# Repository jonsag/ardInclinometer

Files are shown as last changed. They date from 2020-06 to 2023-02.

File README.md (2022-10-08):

# ardInclinometer

An inclinometer built around MPU-6050 and ATmega MCUs  

Works on Arduino UNO, not working on barebone MCUs yet.

## Install latest avrdude from git repository

Install prerequisites  
>$ sudo apt install git build-essential cmake libelf-dev libusb-dev libusb-1.0-0-dev libhidapi-dev libftdi-dev libftdi1-dev flex bison  

Download repository  
>$ git clone [https://github.com/avrdudes/avrdude.git](https://github.com/avrdudes/avrdude.git)  

Build  
>$ cd avrdude  
>$ cmake -D CMAKE_BUILD_TYPE=Release -B build_linux  
>$ cmake --build build_linux  

Install (if you have ~/bin in your path)  
>$ cp -r build_linux/src ~/bin/avrdude-bin  
>$ ln -s avrdude-bin/avrdude ~/bin/avrdude  

Check version  
>$ avrdude -?  

    ...
    avrdude version 7.0-20220924 (8f478f0), URL: <https://github.com/avrdudes/avrdude>

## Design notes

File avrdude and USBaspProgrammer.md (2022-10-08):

# avrdude and USBaspProgrammer

## Hardware

### USBaspProgrammer

I'm using [my version](https://github.com/jonsag/usbaspprogrammer) of [Thomas Fischl's programmer](https://www.fischl.de/usbasp/)  

### ATmega board detector

Not necessary, but I find [this](https://github.com/jonsag/ardAVRProgrammer) useful  

### High voltage programmer

I use [this one](https://github.com/jonsag/ardHighVoltageProgrammer)  

## Software

### picocom

>$ picocom -b 115200 /dev/ttyUSB0 --omap crcrlf  

Exit with  
> [Ctrl+a] [Ctrl+x]

### cu

>$ cu -l /dev/ttyUSB0 -s 115200

Exit with
>~.

## Usage

### How to use avrdude

Check  
>$ avrdude -p m328p -c usbasp -v  

Read fuses  
>$ avrdude -p m328p -c usbasp -U lfuse:r:-:i -U hfuse:r:-:i -U efuse:r:-:i -v  

Erase flash  
$ /usr/bin/avrdude -p m328p -c usbasp -t  

    avrdude: AVR device initialized and ready to accept instructions  

    Reading | ################################################## | 100% 0.00s  

>avrdude> erase  

    >>> erase  
    avrdude: erasing chip  
    avrdude>  

or simply
>$ avrdude -p m88p -c usbasp -e  

#### Set fuses

Use [the calculator](https://www.engbedded.com/fusecalc/)  

>$ avrdude -p m328p -c usbasp -U lfuse:w:0xe2:m -U hfuse:w:0xdb:m -U efuse:w:0xfd:m -v

### Programming an ATmega328P  with external clock

Either you hook it up with an oscillator circuit, or you reset the fuses

#### Fuses examples (obtained with the ATmega board detector)

Example output of a programmed 328P with external clock  

    LFuse = 0xF7 
    HFuse = 0xD9 
    EFuse = 0xFC

An unprogrammed 328P with stock fuses

    LFuse = 0xE2 
    HFuse = 0xDB 
    EFuse = 0xFD

#### Use the high voltage programmer

>$ cu -l /dev/ttyUSB0 -s 9600

    Connected.
    Select mode:
    1: ATmega (28-pin)
    2: ATtiny2313
    3: ATtiny (8-pin) / HVSP
    Selected mode: ATMEGA
    Insert target AVR and press button.

    Existing fuse values:
    LFUSE: F7
    HFUSE: D6

    Enter desired LFUSE hex value (ie. 0x62): 62 (enter 0xE2)
    Enter desired HFUSE hex value (ie. 0xDF): 5B (enter 0xDA)
    Burning fuses...

    Read LFUSE: 62
    Read HFUSE: 5B
    Burn complete.

    It is now safe to remove the target AVR.

    Insert target AVR and press button.

Fuses OK (E:FD, H:DA, L:E2)  
Fuses OK (E:FD, H:D6, L:E2)  
Fuses OK (E:FD, H:D6, L:F7)  

## ATmega328 fuses

stock/empty ATmega328

    Signature = 0x1E 0x95 0x14 
    Processor = ATmega328
    Flash memory size = 32768 bytes.
    LFuse = 0xE2 
    HFuse = 0xDB 
    EFuse = 0xFF 
    Lock byte = 0xFF 
    Clock calibration = 0xA8 
    Bootloader in use: No
    EEPROM preserved through erase: No
    Watchdog timer always on: No
    Bootloader is 2048 bytes starting at 7800

with bootloader from arduino ide

    Signature = 0x1E 0x95 0x14 
    Processor = ATmega328
    Flash memory size = 32768 bytes.
    LFuse = 0xF7 
    HFuse = 0xD6 
    EFuse = 0xFD 
    Lock byte = 0xFF 
    Clock calibration = 0xA8 
    Bootloader in use: Yes
    EEPROM preserved through erase: Yes
    Watchdog timer always on: No
    Bootloader is 512 bytes starting at 7E00

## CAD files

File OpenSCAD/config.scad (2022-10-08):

// config.scad, configuration for ardInclinometer-ATmega328-casing.scad

print = true;

showBoard = true;

showBox = true;
showButtonRods = false;
showLid = false;

// PCB size in mm
pcbX = 66.675;
pcbY = 55.580;
pcbZ = 1.6;

pcbZadj = 0;
boardZ = 13.8 + pcbZadj;

displayX = 25.400;
displayY = 10.050;

displayXoffset = -3.165 / 2;
displayYoffset = 12.420 / 2;

ledDia = 5.5;

buttonRodDia = 5;
buttonRodStickOut = 0;
buttonGuideZ = 9.2 + pcbZadj;

ledTunnelZ = 12 + pcbZadj;

// outer shell
wallThickness = 1;

boxCornerRadius = 5;

// lid
lidClearance = 0.5;
lidScrewHoleDia = 3.5;
lidScrewHeadDia = 5;

textFont = "Liberation Sans:style=Bold";
textSize1 = 5;
textSize2 = 2.5;
textSize3 = 5;
textSize4 = 3;

text1 = "ardInclinometer";
text2 = "github.com/jonsag/ardInclinometer";

// screw posts
lidPostDia = boxCornerRadius * 2;
lidPostHoleDia = 5;
lidPostInset = 1;

pcbPostZ = 15.75 + pcbZadj;
pcbPostDia = 7.5;
pcbPostHoleDia = 5;

// casing measurements
extraSpace = 1;

boxX = pcbX + wallThickness * 2 + extraSpace * 2;
boxY = pcbY + wallThickness * 2 + extraSpace * 2;
boxZ = 35;

lidPostZ = boxZ - pcbPostZ - pcbZ;

roundness = 100;

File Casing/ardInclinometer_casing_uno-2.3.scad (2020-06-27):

// ardInclinometer_casing

// Casing for the ardInclinometer project
// This holds the MPU605 with it's gimbal,
// an arduino, OLED

// what should we draw:
casing = true;
lid = false;

mount1 = false;
mount2 = false;
mount3 = false;

disableAdjustmentHoles = false;

// lay out everything for printing
print = true;

// main body
// width = X, depth = Z, height = Y
width = 125;
depth = 115;
height = 45;

wallThickness = 3;

// oversize factor
overSizeFactor = 1.05; // useful for when making holes, larger than 1

// battery compartment
batteryHeight = 55;
batteryWidth = 20;

// screen wedge
wedgeHeight = 30;

// push buttons
include <push_button.scad>

pushButtonHoleDia = 7;

pushButtonDist = 15;

buttonsXPlaceFactor = 0.295; // a value between 0 and 1
buttonsYPlaceFactor = 0.35;

// power switch
include <power_switch.scad>

totalWidth = 20;
holeWidth = 10.5;
holeDepth = 7;
screwHoleWidth = 15;
screwHoleDia = 2;
knobHoleWidth = 6;
knobDepth = 3;
knobWidth = 3;
knobHeight = 5;
mountPlateHeight = 0.5;
bodyHeight = 5;
legWidth = 1.5;
legDepth = 0.5;
legLength = 3;
legSpacing = 2.54;

// LEDs
include <led.scad>

ledDia = 5;

ledDist = 7; // distance between the leds

ledsXPlaceFactor = 0.355;
ledsYPlaceFactor = 1.5;

// screen cut out and screw posts
screenPostHoriDist = 20;
screenPostVertDist = 22;

screenPostDia = 4;
screenPostHeight = 3;

screenPostHoleDia = 2.5;
screenPostHoleDepth = 3;

screenWidth = 23;
screenHeight = 11.5;
screenOffset = 2.25;

screenCoverOverSize = 1;
screenCoverRecess = 2;

screenXPlaceFactor = 0.75; // a value between 0 and 1
     
// lid screw posts
lidPostDia = 10;
lidPostHoleDia = 2.5;

lidPostHoleDepth = 10;

lidPostOffset = -1; // extra distance from walls to screw posts

// lid
lidThickness = 5;
lidRest = 3;

lidGap = 0.5; // gap between lid and casing

lidScrewHoleDia = 3.5;
lidScrewHeadDia = 6;
lidScrewCountersink = 3;

lidRecess = 2;

// print text on lid
textOnLid1 = "ardInclinometer";
textOnLid2 = "by Jon Sagebrand";

lidTextFont = "Liberation Sans:style=Bold Italic";
lidFontSize = 6;

// mpu6050
include <mpu_mount-2.0.scad>;

adjustmentHoleDia = 3;

// pcb mount
pcbLength = 81.28;
pcbWidth = 45.085;

pcbMountEdgeDist = 3.175;

pcbMountPostHeight = 10;
pcbMountPostDia = 6;

pcbMountScrewDia = 3;

// uno
include <Arduino.scad>

unoPostHeight = 5;
unoPostDia = 6;

//mpu6050_mount();
if (!print) {
     translate([mount1Width / 2 + wallThickness + lidPostDia + lidPostOffset, (mount1Height  + swivelWidth) * 3 + wallThickness - swivelWidth, mount3Depth / 2 + mount3ExtraDepth + wallThickness])
	  rotate([-90, 0, 0])
	  union() {
	  if (mount1) {
	       mount1();
	  }
	  if (mount2) {
	       translate([0, 0, -swivelWidth - mount1Height])
		    mount2();
	  }
	  if (mount3) {
               translate([0, 0, -swivelWidth * 2 - mount1Height * 2])
                    mount3();
	  }
	  if (!print) {
	       translate([-10.5, -7.8 + mount1YMove, mount1Height / 2 - 1.2])
		    mpu6050_gy521();
	  }
     }
} else {
     if (mount1) {
	  translate([width + mount1Width / 2 + 2, mount1Depth / 2, mount1Height / 2 + swivelWidth])
	       mount1();
     }
     if (mount2) {
	  translate([width + mount2Width/ 2 + 2, mount1Depth / 2 + mount2Depth + 2 + mount1YMove, mount2Height / 2 + swivelWidth])
	       mount2();
     }

     if (mount3) {
          translate([width + mount2Width / 2 + 2, mount1Depth / 2 + mount2Depth + 2 + mount2ExtraDepth + 2 + mount2Depth + 2, mount3Height / 2])
               mount3();
     }
}

// roundness
$fn=100;

// start drawing
if (casing) { // create the main body
     union() { // union of drilled main body, screen wedge with cut out and screen screw posts
	  difference() { // drill lid posts screw holes and cut off wedge for screen mount
	       union() { // union of main body, lid rests and screw posts
		    difference() {
			 cube([width, depth, height]); // create the main body
			 
			 // hollow out the casing
			 translate([wallThickness, wallThickness, wallThickness])
			      cube([width - 2 * wallThickness, depth - 2 * wallThickness, height]);			      
		    }
		    lidRests(); // add the prisms where the lid is resting
		    
		    screwPosts(); // add the screwposts where to screw down the lid

		    powerSwitchMount();
	       }
	       screwPostHoles(); // drill the holes in the screw posts
	       
	       wedgeCutOff(0); // cut off the wedge where the screen lies

	       powerSwitchHoles();
	  }
	  
	  difference() {
	       wedgeCutOff(0); // create the cutoff again, this time it's solid
	       
	       wedgeCutOff(wallThickness * sqrt(2)); // move the wedge and cut off again
	       
	       screenCutOut(); // cut out for the screen and screen cover

	       pushButtonHoles(); // drill the holes for the pushbutton

	       ledHoles();
	       
	       if (!disableAdjustmentHoles) {
		    adjustmentHoles(); // drill the holes where to insert an adjustment tool
	       }
	  }
	  pushButtons();

	  leds();
	  
	  screenPosts(); // add screw posts for the screen

	  add_mount4(); // add mount for the mpu

	  batteryCompartment(); // add battercompartment

	  //pcbMount(); // add PCB mount posts

	  unoMount(); // the mount posts for the arduino uno
     }
}

module unoMount() {
     translate([width - wallThickness - 69 - 2, batteryWidth + wallThickness * 2 + lidRest + 53 + 2, wallThickness + unoPostHeight])
	  rotate([0, 0, -90])
	  union() {
	  unoMountPosts(unoPostHeight, unoPostDia);
	  
	  if (!print) {
	       arduinoUno();
	  }
     }    
}


if (lid) { // create the lid
     if (print) {
	  translate ([wallThickness + lidGap, depth + 2, 0])
	       drawLid();
     } else {
	  translate ([wallThickness + lidGap, wallThickness + lidGap, height - lidThickness])
	       drawLid();
     }
}

if (!print) {
     translate([width * screenXPlaceFactor, depth - wedgeHeight / 2 - 1, wedgeHeight / 2 + 3]) // this placement is just an estimation, not critical
	  rotate([-45, 180, 0])
	  translate([-12.5, -13.5, -1.6])
	  GM009605v4();
}

module pcbMount() {
     translate([width - wallThickness - pcbLength / 2 - 3, depth - wedgeHeight - pcbWidth / 2, wallThickness + pcbMountPostHeight / 2])
	  union() {
     if (!print) { // PCB
	  translate([0, 0, pcbMountPostHeight / 2 + 0.6])
	       difference() {
	       color([30/255, 114/255, 198/255])
		    cube([pcbLength, pcbWidth, 1.2], center = true);

	       translate([-pcbLength / 2 + pcbMountEdgeDist, -pcbWidth / 2 + pcbMountEdgeDist, 0])
		    cylinder(1.2, (pcbMountScrewDia + 0.5) / 2, (pcbMountScrewDia + 0.5) / 2, center = true);

	       translate([pcbLength / 2 - pcbMountEdgeDist, -pcbWidth / 2 + pcbMountEdgeDist, 0])
                    cylinder(1.2, (pcbMountScrewDia + 0.5) / 2, (pcbMountScrewDia + 0.5) / 2, center = true);

	       translate([pcbLength / 2 - pcbMountEdgeDist, pcbWidth / 2 - pcbMountEdgeDist, 0])
                    cylinder(1.2, (pcbMountScrewDia + 0.5) / 2, (pcbMountScrewDia + 0.5) / 2, center = true);
	       }
     }

     difference() {
	  union() { // pcb mount posts
	       translate([-pcbLength / 2 + pcbMountEdgeDist, -pcbWidth / 2 + pcbMountEdgeDist, 0])
                    cylinder(pcbMountPostHeight, pcbMountPostDia / 2, pcbMountPostDia / 2, center = true);
	       
               translate([pcbLength / 2 - pcbMountEdgeDist, -pcbWidth / 2 + pcbMountEdgeDist, 0])
                    cylinder(pcbMountPostHeight, pcbMountPostDia / 2, pcbMountPostDia / 2, center = true);
	       
               translate([pcbLength / 2 - pcbMountEdgeDist, pcbWidth / 2 - pcbMountEdgeDist, 0])
                    cylinder(pcbMountPostHeight, pcbMountPostDia / 2, pcbMountPostDia / 2, center = true);

	       translate([-pcbLength / 2 + pcbMountEdgeDist, pcbWidth / 2 - pcbMountEdgeDist, 0])
                    cylinder(pcbMountPostHeight, pcbMountPostDia / 2, pcbMountPostDia / 2, center = true);
	  }
	  union() { // pcb mount posts drill holes                                                         
               translate([-pcbLength / 2 + pcbMountEdgeDist, -pcbWidth / 2 + pcbMountEdgeDist, 0])
                    cylinder(pcbMountPostHeight, (pcbMountScrewDia - 0.5) / 2, (pcbMountScrewDia - 0.5) / 2, center = true);

               translate([pcbLength / 2 - pcbMountEdgeDist, -pcbWidth / 2 + pcbMountEdgeDist, 0])
                    cylinder(pcbMountPostHeight, (pcbMountScrewDia - 0.5) / 2, (pcbMountScrewDia - 0.5) / 2, center = true);

               translate([pcbLength / 2 - pcbMountEdgeDist, pcbWidth / 2 - pcbMountEdgeDist, 0])
                    cylinder(pcbMountPostHeight, (pcbMountScrewDia - 0.5) / 2, (pcbMountScrewDia - 0.5) / 2, center = true);

               translate([-pcbLength / 2 + pcbMountEdgeDist, pcbWidth / 2 - pcbMountEdgeDist, 0])
                    cylinder(pcbMountPostHeight, (pcbMountScrewDia - 0.5) / 2, (pcbMountScrewDia - 0.5) / 2, center = true);
          }

     }
     }
     
}
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

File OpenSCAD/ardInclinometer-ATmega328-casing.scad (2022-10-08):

// ardInclinometer-ATmega328-casing.scad

include <./config.scad>
include <./roundedcube.scad>

module drawAll()
{
	if (showBoard && !print)
		drawBoard();

	if (showBox)
		drawBox();

	if (showButtonRods)
	{
		rodsZ = print ? buttonGuideZ + wallThickness * 1.5 : 0;

		rodsRotY = print ? 180 : 0;

		translate([ 0, 0, rodsZ - buttonRodStickOut - 0.3 ])
		rotate([ 0, rodsRotY, 0 ])
		drawButtonRods();
	}

	if (showLid)
	{
		lidX = print ? boxX * 2 : 0;
		lidZ = print ? boxZ : 0;

		lidRotY = print ? 180 : 0;

		translate([ lidX, 0, lidZ ])
		rotate([ 0, lidRotY, 0 ])
		drawLid();
	}
}

module drawBoard()
{
	color("blue") translate([ boxX / 2 + pcbX / 2, boxY / 2 - pcbY / 2, boardZ + wallThickness ])
	rotate([ 0, 180, 0 ])
	import("../KiCad/ardInclinometer-ATmega328/ardInclinometer-ATmega328-0.1-origin.stl", convexity = 5);
}

module drawBox()
{
	translate([ 0, 0, 0 ])
	{
		difference()
		{
			union() // this is added
			{
				difference()
				{
					roundedcube([ boxX, boxY, boxZ ], false, boxCornerRadius, "z");

					translate([ wallThickness, wallThickness, wallThickness ])
					roundedcube([ boxX - wallThickness * 2, boxY - wallThickness * 2, boxZ ], false, boxCornerRadius,
					            "z");

					// LED holes
					for (i = [-6.985 * 2:6.985:6.985 * 2])
					{
						translate([ boxX / 2 + i - 2.2225, boxY / 2 - 14.46, -wallThickness / 2 ])
						// translate([ boxX / 2 + pcbX / 2, boxY / 2 - pcbY / 2, boardZ ])
						cylinder(h = wallThickness * 2, d = ledDia, center = false, $fn = roundness);
					}

					// button holes
					for (i = [-8.255 * 2:8.255:8.255 * 2])
					{
						translate([ boxX / 2 - 28.2575, boxY / 2 + i, -wallThickness / 2 ])
						cylinder(h = wallThickness * 2, d = buttonRodDia + 0.5, center = false, $fn = roundness);
					}
				}

				// pcb screw posts
				for (i = [3.81:pcbX - 3.81 * 2:pcbX - 3.81])
				{
					for (j = [3.81:pcbY - 3.81 * 2:pcbY - 3.81])
					{
						translate(
						    [ i + boxX / 2 - pcbX / 2, j + boxY / 2 - pcbY / 2, pcbPostZ / 2 - wallThickness / 2 ])
						difference()
						{
							cylinder(h = pcbPostZ - wallThickness, d = pcbPostDia, center = true, $fn = roundness);
							translate([ 0, 0, wallThickness ])
							color("red") cylinder(h = pcbPostZ, d = pcbPostHoleDia, center = true, $fn = roundness);
						}
					}
				}

				// LED tunnels
				for (i = [-6.985 * 2:6.985:6.985 * 2])
				{
					translate([ boxX / 2 + i - 2.2225, boxY / 2 - 14.46, 0 ])
					difference()
					{
						cylinder(h = ledTunnelZ, d = ledDia + 2.5, center = false, $fn = roundness);
						translate([ 0, 0, -wallThickness / 2 ])
						cylinder(h = ledTunnelZ + wallThickness, d = ledDia + 0.5, center = false, $fn = roundness);
					}
				}

				// button guides
				for (i = [-8.255 * 2:8.255:8.255 * 2])
				{
					translate([ boxX / 2 - 28.2575, boxY / 2 + i, 0 ])
					difference()
					{
						cylinder(h = buttonGuideZ, d = buttonRodDia + wallThickness * 4, center = false,
						         $fn = roundness);
						translate([ 0, 0, -wallThickness / 2 ])
						cylinder(h = ledTunnelZ + wallThickness, d = buttonRodDia + 0.5, center = false,
						         $fn = roundness);
					}
				}
			}

			// this will be deleted

			// display hole
			color("red") translate([
				boxX / 2 - displayX / 2 + displayXoffset, boxY / 2 - displayY / 2 + displayYoffset, -wallThickness / 2
			])
			cube(size = [ displayX, displayY, wallThickness * 2 ], center = false);
			//}

			// LED text
			for (i = [-6.985 * 2:6.985:6.985 * 2])
			{
				color("red") translate([ boxX / 2 + i - 2.2225, boxY / 2 - 14.46 - 7, -wallThickness * 1.5 ])
				linear_extrude(wallThickness * 2)

				    if (i == -6.985 * 2)
				{
					text(text = "++", font = textFont, size = textSize3, valign = "center", halign = "center");
				}
				else if (i == -6.985)
				{
					text(text = "+", font = textFont, size = textSize3, valign = "center", halign = "center");
				}
				else if (i == 0)
				{
					text(text = "0", font = textFont, size = textSize3, valign = "center", halign = "center");
				}
				else if (i > 6.084 && i < 6.986)
				{
					text(text = "-", font = textFont, size = textSize3, valign = "center", halign = "center");
				}
				else if (i == 6.985 * 2)
				{
					text(text = "--", font = textFont, size = textSize3, valign = "center", halign = "center");
				}
			}

			// X arrow
			color("red") translate([ boxX - 5, 5, wallThickness / 2 ])
			rotate([ 0, 180, 0 ])
			linear_extrude(wallThickness * 2)
			    text(text = "-----> X", font = textFont, size = textSize4, valign = "center", halign = "left");

			// Z arrow
			for (i = [0:textSize4 + 2:(textSize4 + 2)])
			{
				color("red") translate([ boxX - 5, 5 + textSize4 + 2 + i, wallThickness / 2 ])
				rotate([ 0, 180, 0 ])
				linear_extrude(wallThickness * 2)
				    text(text = "|", font = textFont, size = textSize4, valign = "center", halign = "left");
			}

			color("red") translate([ boxX - 4.5, 5 + textSize4 + 2 * 5, wallThickness / 2 ])
			rotate([ 0, 180, 0 ])
			linear_extrude(wallThickness * 2)
			    text(text = "^", font = textFont, size = textSize4, valign = "center", halign = "left");

			color("red") translate([ boxX - 4.5, 5 + textSize4 + 2 * 7, wallThickness / 2 ])
			rotate([ 0, 180, 0 ])
			linear_extrude(wallThickness * 2)
			    text(text = "Z", font = textFont, size = textSize4, valign = "center", halign = "left");

			// Y arrow
			color("red") translate([ boxX - wallThickness / 2, 5, 5 ])
			rotate([ 0, 90, 0 ])
			linear_extrude(wallThickness * 2)
			    text(text = "Y <-----", font = textFont, size = textSize4, valign = "center", halign = "right");

			// button text
			for (i = [-8.255 * 2:8.255:8.255 * 2])
			{
				color("red") translate([ boxX / 2 - 28.2575 + 5, boxY / 2 + i, wallThickness * 0.5 ])
				rotate([ 0, 180, 0 ])
				linear_extrude(wallThickness * 2)

				    /*if (i == -8.255 * 2)
				    {
				        text(text = "X", font = textFont, size = textSize3, valign = "center", halign = "left");
				    }
				    else*/
				    if (i == -8.255)
				{
					text(text = "ALL", font = textFont, size = textSize2, valign = "center", halign = "right");
				}
				else if (i == 0)
				{
					text(text = "Z", font = textFont, size = textSize3, valign = "center", halign = "right");
				}
				else if (i > 8.254 && i < 8.256)
				{
					text(text = "Y", font = textFont, size = textSize3, valign = "center", halign = "right");
				}
				else if (i == 8.255 * 2)
				{
					text(text = "X", font = textFont, size = textSize3, valign = "center", halign = "right");
				}
			}
		}
	}
}

module drawButtonRods()
{
	for (i = [-8.255 * 2:8.255:8.255 * 2])
	{
		color("black") translate([ boxX / 2 - 28.2575, boxY / 2 + i, -wallThickness / 2 - buttonRodStickOut * 2 - 0.3 ])
		union()
		{
			cylinder(h = buttonGuideZ + wallThickness + buttonRodStickOut, d = buttonRodDia - 0.5);
			translate([ 0, 0, buttonGuideZ + wallThickness + buttonRodStickOut ])
			cylinder(h = wallThickness, d = buttonRodDia + wallThickness * 2);
		}
	}
}

module drawLid()
{
	difference()
	{
		color("lightgreen")
		    translate([ wallThickness + lidClearance / 2, wallThickness + lidClearance / 2, boxZ - wallThickness ])
		union()
		{
			roundedcube(
			    [ boxX - wallThickness * 2 - lidClearance, boxY - wallThickness * 2 - lidClearance, wallThickness ],
			    false, boxCornerRadius, "z");

			// pcb screw posts
			for (i = [3.81:pcbX - 3.81 * 2:pcbX - 3.81])
			{
				for (j = [3.81:pcbY - 3.81 * 2:pcbY - 3.81])
				{
					translate(
					    [ i + boxX / 2 - pcbX / 2, j + boxY / 2 - pcbY / 2, 0 ]) // pcbPostZ / 2 - wallThickness / 2 ])
					translate([ -wallThickness - lidClearance / 2, -wallThickness - lidClearance / 2, -lidPostZ / 2 ])
					cylinder(h = lidPostZ, d = pcbPostDia, center = true, $fn = roundness);
				}
			}
		}

		// text on lid
		color("red") translate([ boxX / 2, boxY / 2 + textSize1, boxZ - wallThickness / 2 ])
		linear_extrude(wallThickness)
		    text(text = str(text1), font = textFont, size = textSize1, valign = "center", halign = "center");

		color("red") translate([ boxX / 2, boxY / 2 - textSize2, boxZ - wallThickness / 2 ])
		linear_extrude(wallThickness)
		    text(text = str(text2), font = textFont, size = textSize2, valign = "center", halign = "center");
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

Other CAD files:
OpenSCAD/roundedcube.scad
OpenSCAD/Uno casing/ardInclinometer_casing.scad
OpenSCAD/Uno casing/ardInclinometer_casing_uno.scad
OpenSCAD/Uno casing/mpu_mount.scad

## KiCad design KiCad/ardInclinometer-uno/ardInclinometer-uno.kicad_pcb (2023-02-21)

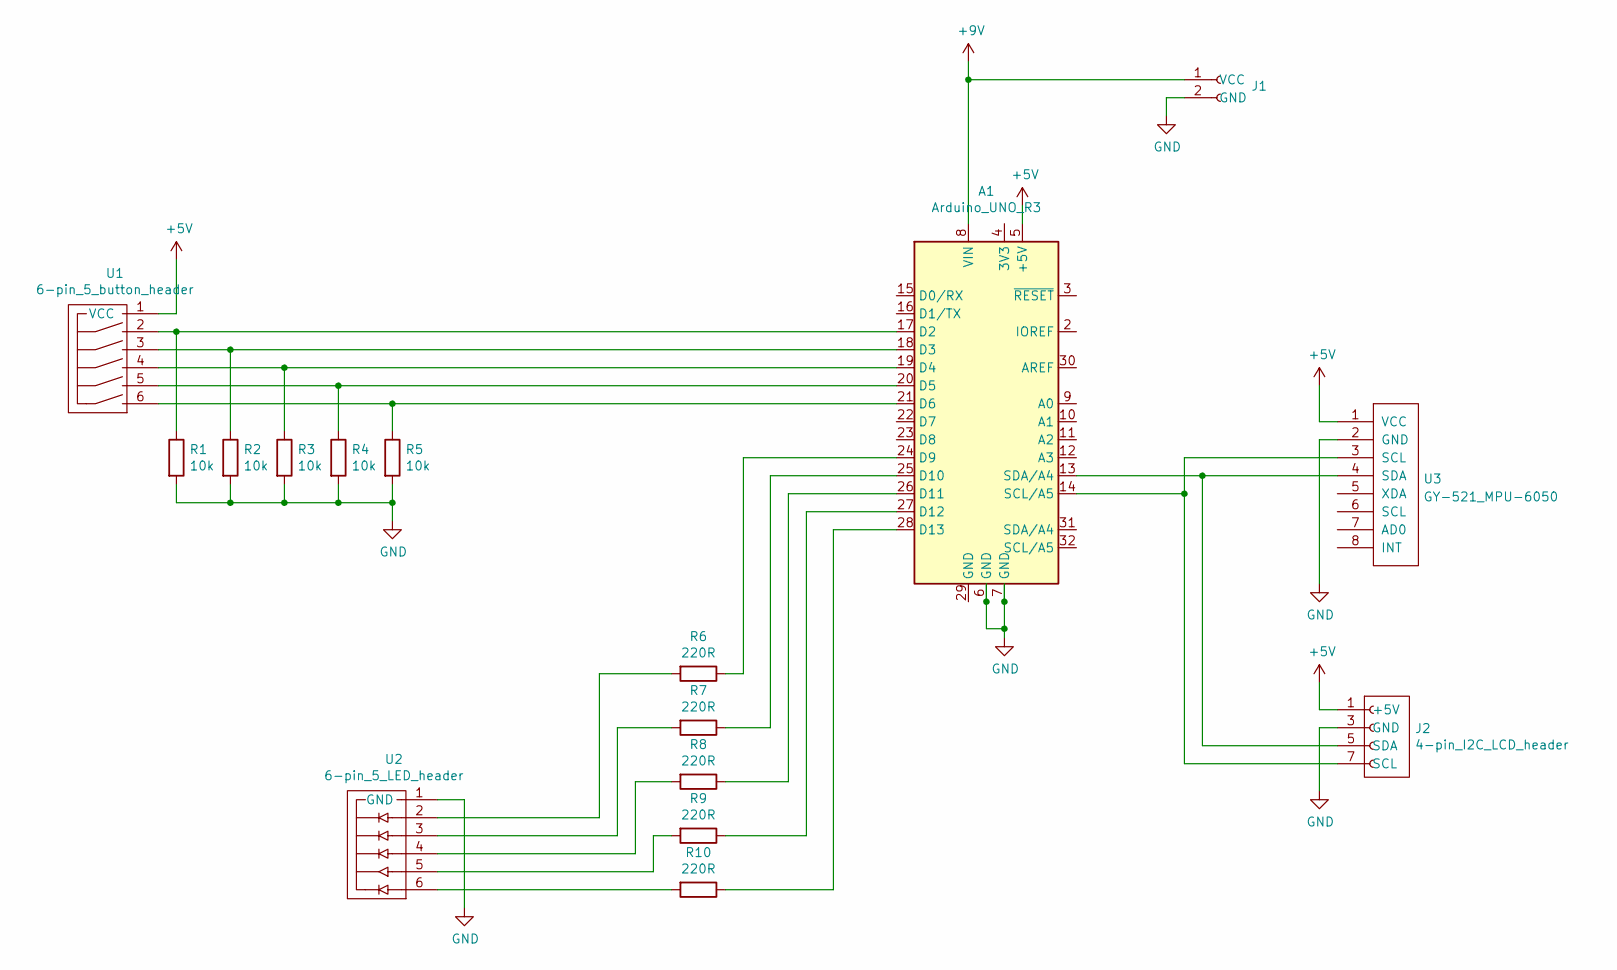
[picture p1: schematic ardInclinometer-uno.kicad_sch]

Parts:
A1: Arduino_UNO_R3; Arduino_UNO_R3_shield_large
J1: 2-pin_power_input_header; 2-pin_power_input_header_larger_pads
J2: 4-pin_I2C_LCD_header; 4-pin_I2C_LCD_header_larger
R1, R2, R3, R4, R5: 10k; R_Axial_DIN0207_L6.3mm_D2.5mm_P10.16mm_Horizontal_larger_pa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
R6, R7, R8, R9, R10: 220R; R_Axial_DIN0207_L6.3mm_D2.5mm_P10.16mm_Horizontal_larger_pa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
U1: 6-pin_5_button_header; 6-pin_5_switch_header_large
U2: 6-pin_5_LED_header; 6-pin_5_LED_header_large
U3: GY-521_MPU-6050

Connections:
+5V: A1.5 (+5V), J2.1 (+5V), U1.1 (VCC), U3.1 (VCC)
+9V: A1.8 (VIN), J1.1 (VCC)
GND: A1.6 (GND), A1.7 (GND), J1.2 (GND), J2.3 (GND), R1.2, R2.2, R3.2, R4.2, R5.2, U2.1 (GND), U3.2 (GND)
unnamed: A1.13 (SDA/A4), J2.5 (SDA), U3.4 (SDA)
unnamed: A1.14 (SCL/A5), J2.7 (SCL), U3.3 (SCL)
unnamed: A1.17 (D2), R1.1, U1.2
unnamed: A1.18 (D3), R2.1, U1.3
unnamed: A1.19 (D4), R3.1, U1.4
unnamed: A1.20 (D5), R4.1, U1.5
unnamed: A1.21 (D6), R5.1, U1.6
unnamed: A1.24 (D9), R6.1
unnamed: A1.25 (D10), R7.1
unnamed: A1.26 (D11), R8.1
unnamed: A1.27 (D12), R9.1
unnamed: A1.28 (D13), R10.1
unnamed: R6.2, U2.2
unnamed: R7.2, U2.3
unnamed: R8.2, U2.4
unnamed: R9.2, U2.5
unnamed: R10.2, U2.6

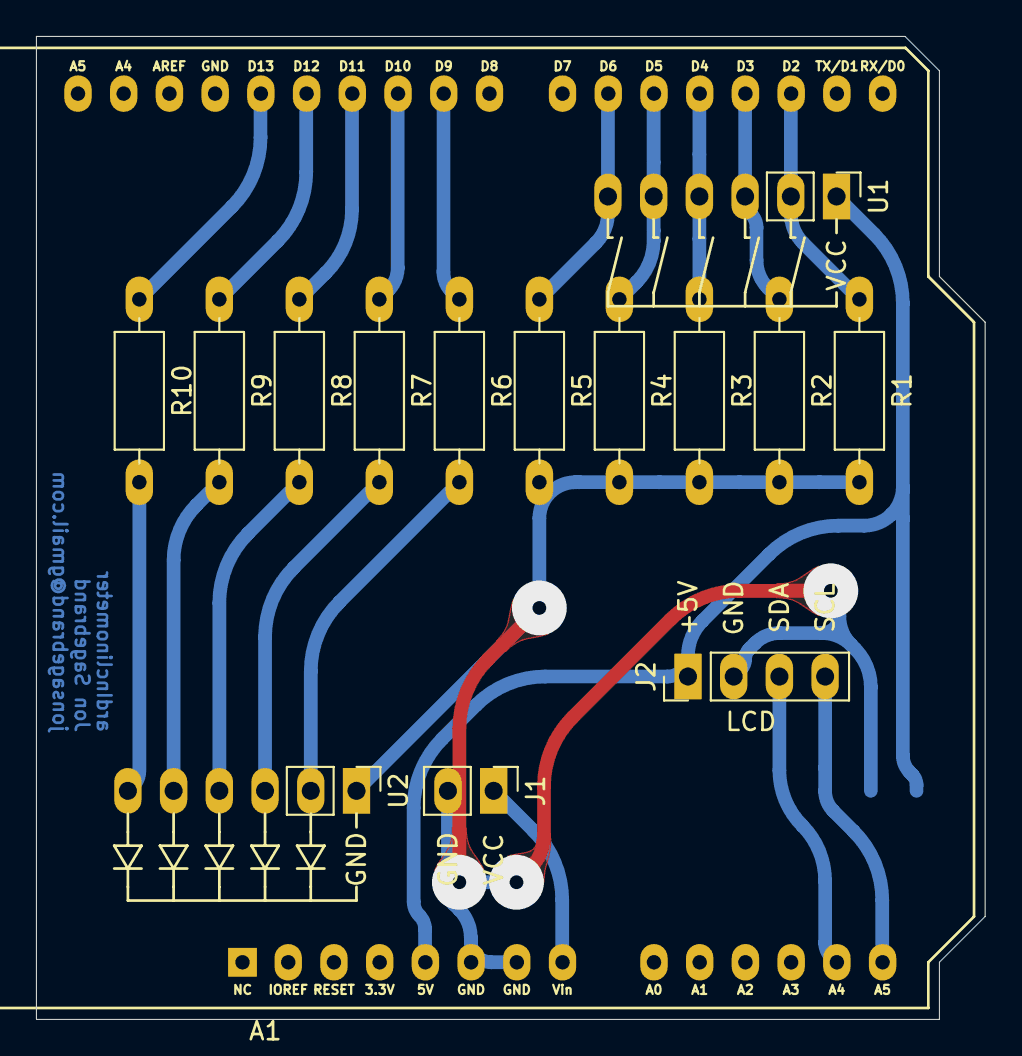
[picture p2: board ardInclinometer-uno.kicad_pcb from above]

Board: 2 copper layers, 52.7 x 54.6 mm, 15 parts (0 on the bottom side), 20 nets.

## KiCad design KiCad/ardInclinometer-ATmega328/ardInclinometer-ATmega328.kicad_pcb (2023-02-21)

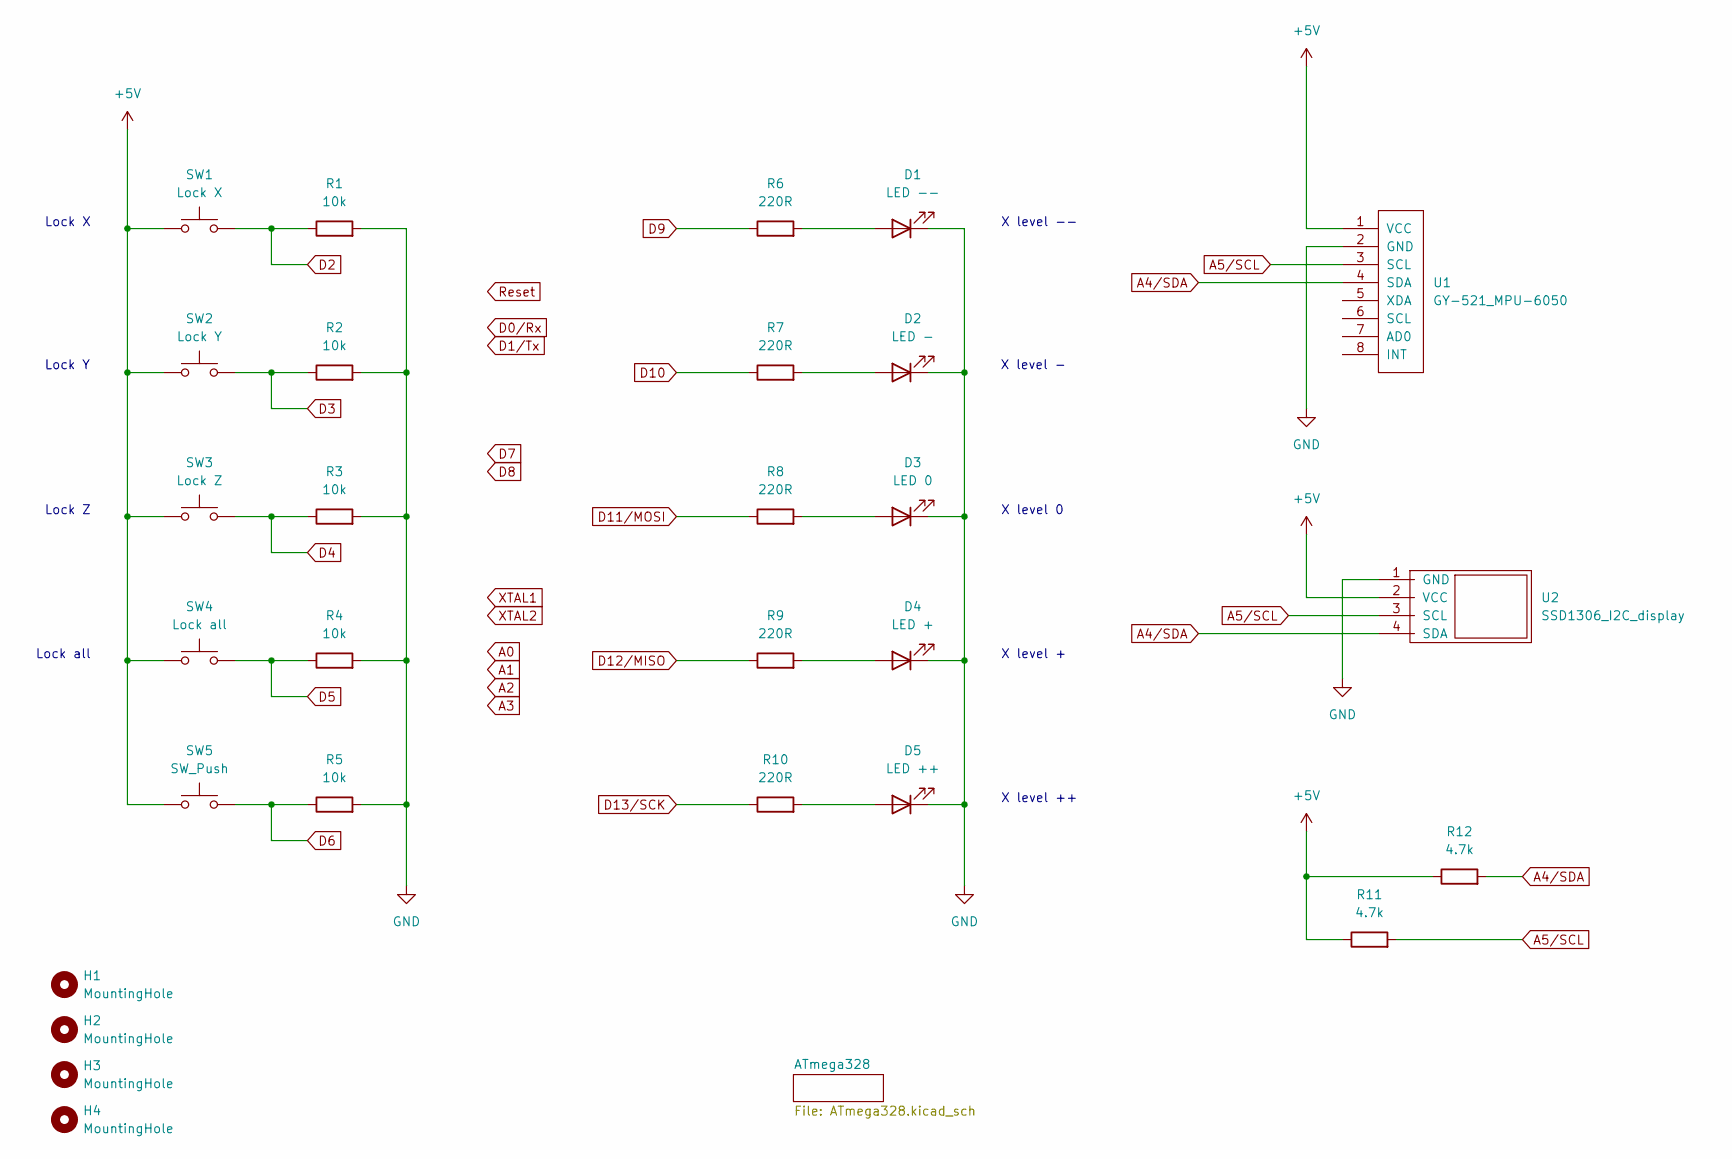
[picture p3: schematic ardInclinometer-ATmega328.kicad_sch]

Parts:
D1: LED --; LED_D5.0mm_large
D2: LED -; LED_D5.0mm_large
D3: LED 0; LED_D5.0mm_large
D4: LED +; LED_D5.0mm_large
D5: LED ++; LED_D5.0mm_large
H1, H2, H3, H4: MountingHole; MountingHole_3.2mm_M3
R1, R2, R3, R4, R5: 10k; R_Axial_DIN0207_L6.3mm_D2.5mm_P10.16mm_Horizontal_larger_pa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
R6, R7, R8, R9, R10: 220R; R_Axial_DIN0207_L6.3mm_D2.5mm_P10.16mm_Horizontal_larger_pa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
R11, R12: 4.7k; R_Axial_DIN0207_L6.3mm_D2.5mm_P10.16mm_Horizontal_large
SW1: Lock X; SW_PUSH_6mm_large
SW2: Lock Y; SW_PUSH_6mm_large
SW3: Lock Z; SW_PUSH_6mm_large
SW4: Lock all; SW_PUSH_6mm_large
SW5: SW_Push; SW_PUSH_6mm_large
U1: GY-521_MPU-6050; GY-521_MPU6050_w_header_large
U2: SSD1306_I2C_display; SSD1306_I2C_0.96_OLED_display_large

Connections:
+5V: R11.1, R12.1, SW1.1, SW2.1, SW3.1, SW4.1, SW5.1, U1.1 (VCC), U2.2 (VCC); also elsewhere on the board
A4/SDA: R12.2, U1.4 (SDA), U2.4 (SDA); also elsewhere on the board
A5/SCL: R11.2, U1.3 (SCL), U2.3 (SCL); also elsewhere on the board
D2: R1.1, SW1.2; also elsewhere on the board
D3: R2.1, SW2.2; also elsewhere on the board
D4: R3.1, SW3.2; also elsewhere on the board
D5: R4.1, SW4.2; also elsewhere on the board
D6: R5.1, SW5.2; also elsewhere on the board
D9: R6.1; also elsewhere on the board
D10: R7.1; also elsewhere on the board
D11/MOSI: R8.1; also elsewhere on the board
D12/MISO: R9.1; also elsewhere on the board
D13/SCK: R10.1; also elsewhere on the board
GND: D1.1 (K), D2.1 (K), D3.1 (K), D4.1 (K), D5.1 (K), R1.2, R2.2, R3.2, R4.2, R5.2, U1.2 (GND), U2.1 (GND); also elsewhere on the board
unnamed: D1.2 (A), R6.2
unnamed: D2.2 (A), R7.2
unnamed: D3.2 (A), R8.2
unnamed: D4.2 (A), R9.2
unnamed: D5.2 (A), R10.2

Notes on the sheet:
X level +
Lock all
Lock Z
X level -
X level ++
Lock X
Lock Y
X level --
X level 0

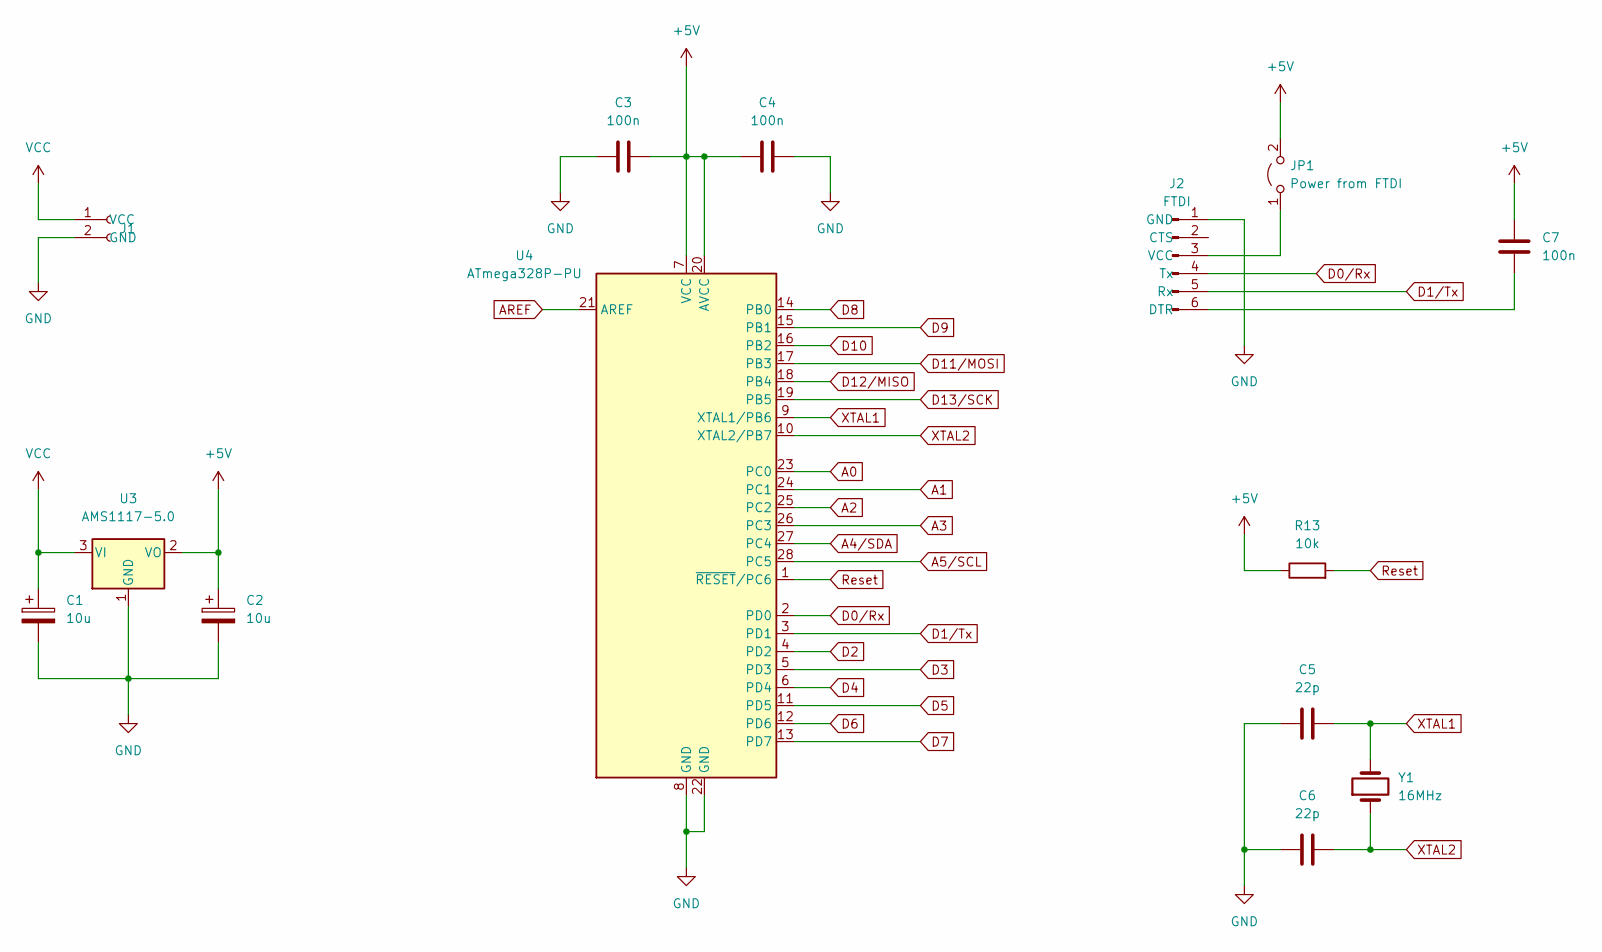
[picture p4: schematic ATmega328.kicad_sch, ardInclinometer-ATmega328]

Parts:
C1, C2: 10u; CP_Radial_D5.0mm_P2.00mm_larger
C3, C4, C7: 100n; C_Disc_D4.3mm_W1.9mm_P5.00mm_large
C5, C6: 22p; C_Disc_D3.0mm_W1.6mm_P2.50mm_larg
J1: Power in; 2-pin_power_input_header_larger_pads
J2: FTDI; 6-pin FTDI Programmer PinSocket large
JP1: Power from FTDI; Jumper_1x02_P2.54mm_large
R13: 10k; R_Axial_DIN0207_L6.3mm_D2.5mm_P10.16mm_Horizontal_larger_pa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
U3: AMS1117-5.0; SOT-223-3_TabPin2
U4: ATmega328P-PU; DIP-28_W7.62mm_LongPads w socket
Y1: 16MHz; Crystal_HC49-4H_Vertical_large

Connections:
+5V: C2.1, C3.1, C4.2, C7.2, JP1.2 (B), R13.1, U3.2 (VO), U4.7 (VCC), U4.20 (AVCC); also elsewhere on the board
A0: U4.23 (PC0)
A1: U4.24 (PC1)
A2: U4.25 (PC2)
A3: U4.26 (PC3)
A4/SDA: U4.27 (PC4); also elsewhere on the board
A5/SCL: U4.28 (PC5); also elsewhere on the board
AREF: U4.21 (AREF)
D0/Rx: J2.4 (Tx), U4.2 (PD0)
D1/Tx: J2.5 (Rx), U4.3 (PD1)
D2: U4.4 (PD2); also elsewhere on the board
D3: U4.5 (PD3); also elsewhere on the board
D4: U4.6 (PD4); also elsewhere on the board
D5: U4.11 (PD5); also elsewhere on the board
D6: U4.12 (PD6); also elsewhere on the board
D7: U4.13 (PD7)
D8: U4.14 (PB0)
D9: U4.15 (PB1); also elsewhere on the board
D10: U4.16 (PB2); also elsewhere on the board
D11/MOSI: U4.17 (PB3); also elsewhere on the board
D12/MISO: U4.18 (PB4); also elsewhere on the board
D13/SCK: U4.19 (PB5); also elsewhere on the board
GND: C1.2, C2.2, C3.2, C4.1, C5.1, C6.1, J1.2 (GND), J2.1 (GND), U3.1 (GND), U4.8 (GND), U4.22 (GND); also elsewhere on the board
unnamed: C7.1, J2.6 (DTR)
unnamed: J2.3 (VCC), JP1.1 (A)
Reset: R13.2, U4.1 (~RESET/PC6)
VCC: C1.1, J1.1 (VCC), U3.3 (VI)
XTAL1: C5.2, U4.9 (XTAL1/PB6), Y1.2
XTAL2: C6.2, U4.10 (XTAL2/PB7), Y1.1

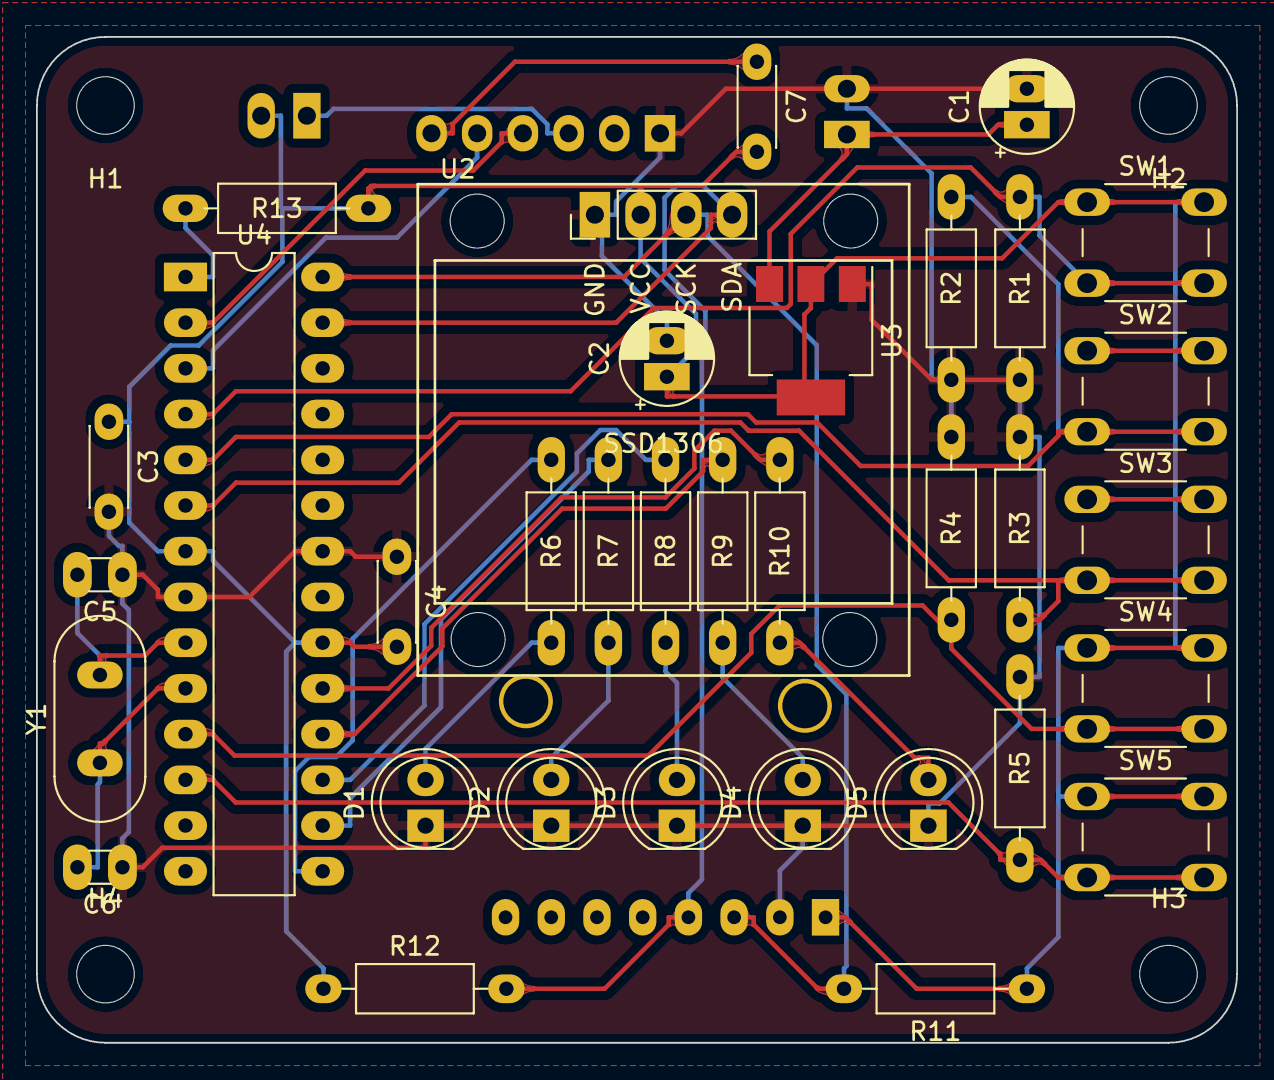
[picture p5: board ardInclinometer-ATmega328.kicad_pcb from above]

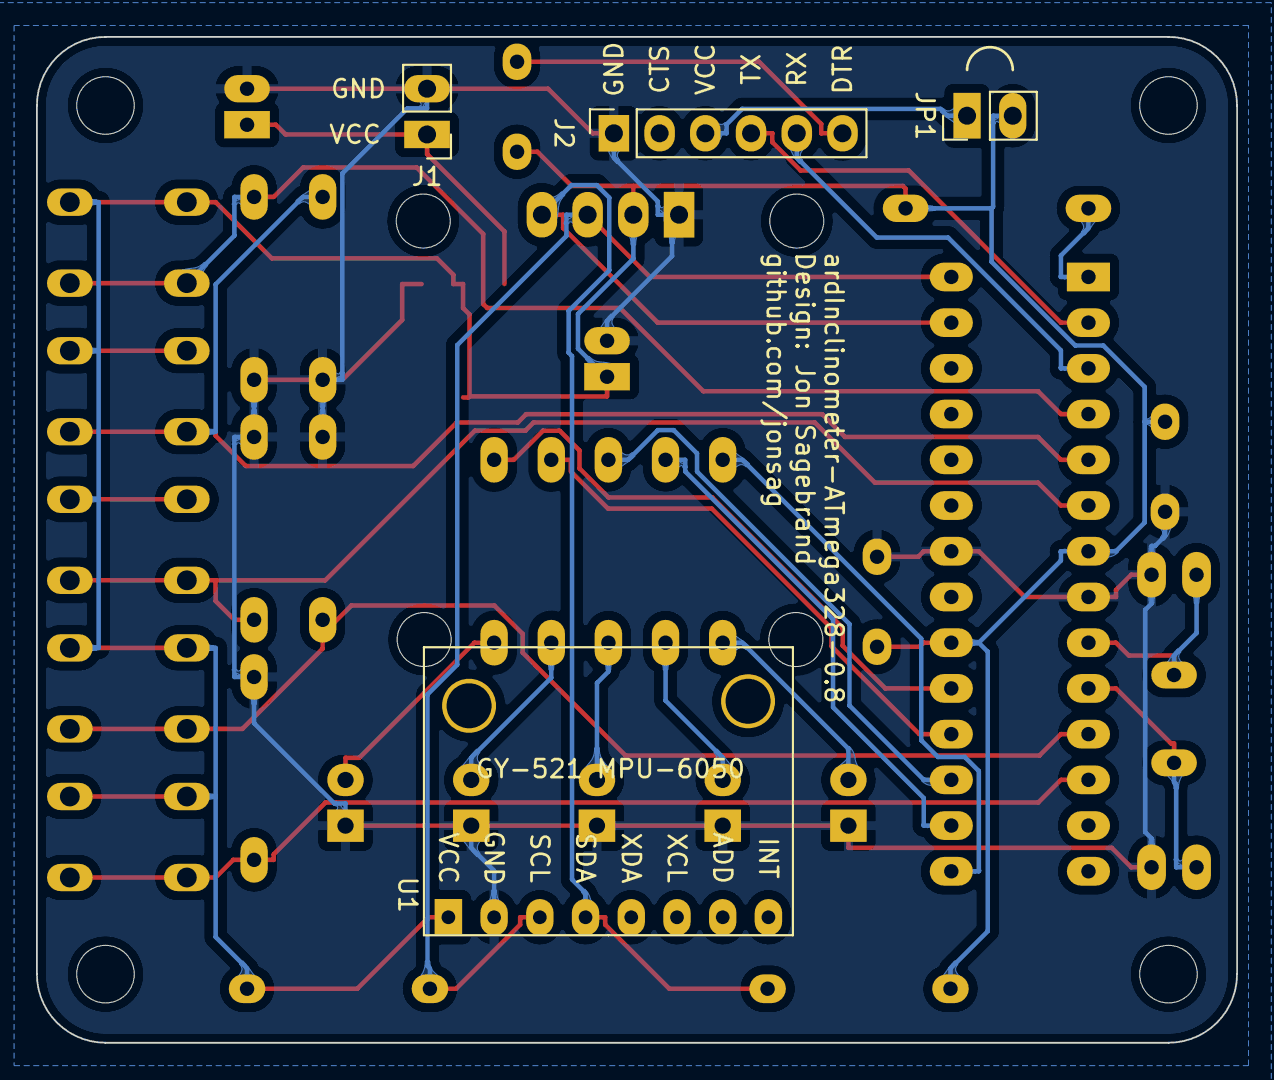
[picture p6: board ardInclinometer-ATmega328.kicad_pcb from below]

Board: 2 copper layers, 66.7 x 55.9 mm, 42 parts (4 on the bottom side), 27 nets.

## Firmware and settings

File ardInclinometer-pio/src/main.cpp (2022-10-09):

#include <Arduino.h>

#include "configuration.h" // sets all variables
#include "maths.h"         // calculations
#include "printOLED.h"     // prints on OLED screen
#include "buttons.h"       // handle button presses
#include "LEDs.h"          // lights up a LED corresponding to X-angle

void setup()
{
  /*******************************
    Wire
  *******************************/
  Wire.begin();

  /*******************************
    OLED
  *******************************/
  Wire.setClock(400000L);

  oled.begin(&Adafruit128x64, I2C_ADDRESS);

  // oled.setFont(Adafruit5x7);
  oled.setFont(System5x7);

  oled.clear();
  oled.println("ardInclinometer");

  /*******************************
    Start serial
  *******************************/
  if (DEBUG || INFO)
  {
    oled.println("Starting serial ...");

    Serial.begin(serialSpeed);
  }
  else
  {
    oled.println();
  }

  /*******************************
    Print start information
  *******************************/
  infoMessln(programName); // print information
  infoMessln(date);
  infoMess("by ");
  infoMessln(author);
  infoMessln(email);
  infoMessln();

  /*******************************
    MPU
  *******************************/
  oled.println("Starting MPU ...");

  infoMessln("=====================================");
  infoMessln("Starting MPU ...");

  mpu6050.begin();

  oled.println("Calibrating ...");

  infoMessln("Starting calibration ...");

  mpu6050.calcGyroOffsets(true);

  oled.println("Calibrating ...");

  infoMessln();

  /*******************************
    In- and outputs
  *******************************/
  oled.println("Starting in-, outputs ...");

  infoMessln("Starting in-, outputs ...");

  pinMode(levelLED_neg1, OUTPUT); // set level LEDs as outputs
  pinMode(levelLED_neg0, OUTPUT);
  pinMode(levelLED_level, OUTPUT);
  pinMode(levelLED_pos0, OUTPUT);
  pinMode(levelLED_pos1, OUTPUT);

  /*******************************
    Setup FTDebouncer pins
  *******************************/
  oled.print("Start debouncer ...");

  infoMessln("Starting debouncer ...");

  pinDebouncer.addPin(lockXButton, LOW, onPinActivated, onPinDeactivated); // pin has external pull-down resistor
  pinDebouncer.addPin(lockYButton, LOW, onPinActivated, onPinDeactivated);
  pinDebouncer.addPin(lockZButton, LOW, onPinActivated, onPinDeactivated);
  pinDebouncer.addPin(lockAllButton, LOW, onPinActivated, onPinDeactivated);
  pinDebouncer.addPin(button5, LOW, onPinActivated, onPinDeactivated);

  pinDebouncer.begin();

  oled.clear();

  infoMessln("Started!");
  infoMessln();

  startMillis = millis();
}

void loop()
{
  pinDebouncer.update(); // reads and handles all buttons

  if (millis() - startMillis < measureTime)
  {
    /*******************************
        Measure angles
    *******************************/
    values++;

    mpu6050.update(); // read values

    angleXAcc += mpu6050.getAngleX();
    angleYAcc += mpu6050.getAngleY();
    angleZAcc += mpu6050.getAngleZ();
  }
  else
  {
    /*******************************
      Calculate angles
    *******************************/
    angleX = round1dec(angleXAcc / values); // calculate averages and round
    angleY = round1dec(angleYAcc / values);
    angleZ = round1dec(angleZAcc / values);

    lightLED(angleX, angleXLock); // light the LED

    if (angleX != oldAngleX)
    {
      printActualAng(0, angleX, angleXLock); // prints the actual values on screen
      oldAngleX = angleX;
    }
    if (angleY != oldAngleY)
    {
      printActualAng(2, angleY, angleYLock);
      oldAngleY = angleY;
    }
    if (angleZ != oldAngleZ)
    {
      printActualAng(4, angleZ, angleZLock);
      oldAngleZ = angleZ;
    }

    angleXAcc = 0; // reset all accumulated values
    angleYAcc = 0;
    angleZAcc = 0;

    values = 0;

    startMillis = millis();
  }

  debugMess("\tAngles, X: ");
  debugMess(angleX);
  debugMess("\tY: ");
  debugMess(angleY);
  debugMess("\tZ: ");
  debugMess(angleZ);

  debugMess("\t");
  debugMess(values);
  debugMess(" values");
  debugMess();

  /*******************************
    Messages
  *******************************/
  if (millis() - messMillis >= messTime)
  {
    mess = "";
  }

  if (mess != oldMess)
  {
    printMess(mess);
    oldMess = mess;
  }
}

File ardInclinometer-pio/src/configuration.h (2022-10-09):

String programName = "ardInclinometer";
String date = "20221009";
String author = "Jon Sagebrand";
String email = "jonsagebrand@gmail.com";

/*******************************
  Serial
*******************************/
#define serialSpeed 9600

/*******************************
  Debugging
*******************************/
#define DEBUG 0 // debugMess is off when 0
#define INFO 1

#if DEBUG
#define debugMess(x) Serial.print(x)
#define debugMessln(x) Serial.println(x)
#else
#define debugMess(x)
#define debugMessln(x)
#endif

#if INFO || DEBUG
#define infoMess(x) Serial.print(x)
#define infoMessln(x) Serial.println(x)
#else
#define infoMess(x)
#define infoMessln(x)
#endif

/*******************************
  Mire
*******************************/
#include <Wire.h> // load the wire library

/*******************************
  MPU-6050
*******************************/
// MPU6050 I2C address: 0x68

#include <MPU6050_tockn.h>

MPU6050 mpu6050(Wire); // start mpu instance

double angleXAcc = 0; // holds the accumulated readings
double angleYAcc = 0;
double angleZAcc = 0;

double angleX = 0; // holds the averaged angles
double angleY = 0;
double angleZ = 0;

double oldAngleX = 0; // holds the old values
double oldAngleY = 0;
double oldAngleZ = 0;

double angleXLock = 0; // stores the locked angles
double angleYLock = 0;
double angleZLock = 0;

boolean angleXLocked = false;
boolean angleYLocked = false;
boolean angleZLocked = false;
boolean anglesLocked = false;

double measureTime = 282; // for how long should values be read before averaged, ms
int values = 0;           // counting values read

/*******************************
  OLED
*******************************/
// OLED screens I2C address: 0x3c

#include "SSD1306Ascii.h"
#include "SSD1306AsciiWire.h"

#define I2C_ADDRESS 0x3C

SSD1306AsciiWire oled; // start oled instance

/*******************************
  FTDebouncer setup
*******************************/
const byte debounceTime = 15;

#if !defined(nullptr)
#define nullptr NULL
#endif

#include "FTDebouncer.h" // load library for debouncing buttons
FTDebouncer pinDebouncer(debounceTime);

/*******************************
  In- and outputs
*******************************/
#define lockXButton 2
#define lockYButton 3
#define lockZButton 4
#define lockAllButton 5
#define button5 6

#define levelLED_neg1 9 // Level LEDs
#define levelLED_neg0 10
#define levelLED_level 11 // at zero
#define levelLED_pos0 12
#define levelLED_pos1 13

/*******************************
  Misc
*******************************/
double startMillis;

String mess = ""; // holds the message
String oldMess = "";

double messMillis;
#define messTime 2000 // how long to show a message, ms

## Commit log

2020-03-14 added KiCad
    [ardInclinometer.kicad_pcb, ardInclinometer.sch]
2020-06-13 first sketch, lights LEDs
2020-06-13 sketch now prints angles to LCD
    [configuration.h]
2020-06-14 prints to OLED, locks angles
    [configuration.h]
2020-06-15 prints messages
    [configuration.h]
2020-06-16 started on a casing
    [ardInclinometer_casing.scad]
2020-06-16 casing has lid
    [ardInclinometer_casing.scad]
2020-06-16 prints text in lid recess
    [ardInclinometer_casing.scad]
2020-06-16 added gy-521 module
    [ardInclinometer_casing.scad, misc_parts.scad]
2020-06-17 added screen wedge
    [ardInclinometer_casing.scad]
2020-06-17 added screen cut out
    [ardInclinometer_casing.scad]
2020-06-17 started with screen mount
    [ardInclinometer_casing.scad]
2020-06-17 screen posts
    [ardInclinometer_casing.scad]
2020-06-18 moved screen posts
    [ardInclinometer_casing.scad]
2020-06-18 started on OLED screen
    [GM009605v4.scad]
2020-06-18 added header comment
    [GM009605v4.scad]
2020-06-19 added button holes
    [ardInclinometer_casing.scad]
2020-06-20 added mount for mpu
    [mpu_mount.scad]
2020-06-20 schematics and casing
    [GM009605v4.scad, ardInclinometer.kicad_pcb, ardInclinometer.sch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]
2020-06-27 uno casing and schematics
    [GM009605v4.scad, ardInclinometer-uno.kicad_pcb, ardInclinometer-uno.sch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]
2021-01-02 added scads
    [Arduino.scad, ardInclinometer_casing.scad, ardInclinometer_casing_uno.scad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]
2022-09-09 atmega328 kicad
    [ATmega328.kicad_sch, ardInclinometer-ATmega328.kicad_pcb, ardInclinometer-ATmega328.kicad_sch]
2022-09-25 atmega casing
    [ardInclinometer-ATmega328-casing.scad, ardInclinometer-ATmega328.kicad_pcb, config.scad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]
2022-09-25 casing looks good for now
    [ardInclinometer-ATmega328-casing.scad, config.scad, roundedcube.scad]
2022-09-27 casing finished
    [ardInclinometer-ATmega328-casing.scad, config.scad]
2022-09-28 new pio environment
    [configuration.h]
2022-10-02 better enclosure
    [ardInclinometer-ATmega328-casing.scad, config.scad]
2022-10-02 better length of lid posts
    [config.scad]
2022-10-04 more text on box
    [ardInclinometer-ATmega328-casing.scad, config.scad]
2022-10-08 new schematics and pcb
    [ATmega328.kicad_sch, ardInclinometer-ATmega328-casing.scad, ardInclinometer-ATmega328.kicad_pcb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]
2022-10-08 more mistakes corrected...
    [ATmega328.kicad_sch, ardInclinometer-ATmega328.kicad_pcb, ardInclinometer-ATmega328.kicad_sch]
2022-10-09 kicad corrections and dev
    [ATmega328.kicad_sch, ardInclinometer-ATmega328.kicad_pcb, ardInclinometer-ATmega328.kicad_sch]
2022-10-09 works on code
    [configuration.h]
2022-10-21 kicad v0.6
    [ATmega328.kicad_sch, ardInclinometer-ATmega328.kicad_pcb, ardInclinometer-ATmega328.kicad_sch]
2022-12-02 added stl of board
